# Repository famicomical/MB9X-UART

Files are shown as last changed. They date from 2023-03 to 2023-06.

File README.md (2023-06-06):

# MB9X-UART
Allows you to program the Fujitsu F2MC-16LX series processors using an RS-232C serial port connection. It uses a 12-pin connector for direct connection to the JVC DT-V series monitors and an optional 10-pin connection as described in Fujitsu documentation. Note: [programming the DT-V monitors](dt-vmod) requires modifying the Signal PWB. 

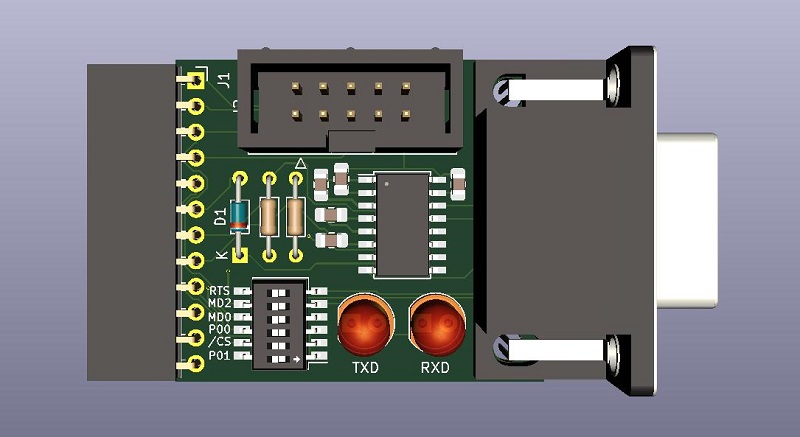
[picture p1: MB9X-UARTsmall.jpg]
PCB


The person assembling this board will need to procure their own USB to RS232-C cable and their own copy of the Fujitsu "FLASH MCU Programmer 16LX" software, which includes proprietary configuration files for the MCUs. I recommend installing [ISP-MB9X](https://isp-mb9x.sourceforge.net/) by Sergey Pinigin in addition to the [Fujitsu software](http://web.archive.org/web/20041020161858/http://www.fme.gsdc.de/products/utilitie.htm) to have some more fine control over programming operations.

## Example Usage
 - Identify the chip you are programming and set the DIP switches accordingly
   - Settings can be found in Fujitsu documentation. The /CS and RTS switches should stay ON.
 - Connect the USB-RS232C port to the assembled MB9X-UART PCB
    - extension of the USB cord is preferable to extending the RS232-C connection. in other words, connect the MB9X-UART directly to your adapter.
 - Connect the MB9X-UART to your target board, and turn on the power
 - Invoke the ISP-MB9X program from the command-line. 
   - For example: ```isp-mb9x.exe /1 /o4 /MB90F553A /b ROM /r```
uses serial port COM1 to dump the ROM from a Fujitsu MB90F553A running at 4MHz into a file called ROM. 
      - Caution: running the program without the /r command will erase the ROM from your MCU by default, so be careful!!
      - you must add the .mhx file extension manually as the isp-mb9x program will crash if you supply a file extension in the command line.
 - Wait for the read to complete being careful not to disturb the cables.
 - Power off your equipment and unplug the board

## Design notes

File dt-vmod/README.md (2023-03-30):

# Serial Programming mod for JVC DT-V Monitors
Some modification is needed to put the MCU in a JVC monitor into serial programming mode. 
We need a way to ground pin P01, and we will accomplish this by cutting an unused clock trace going to the 12-pin serial connector and replacing that signal with P01.
The UART-MB9X device will then be usable on the SIGNAL PWB. 

 - First, remove the 10 screws holding down the monitor cover
 - grabbing by the handles, wiggle the cover towards the back of the monitor slightly until you can see the metal lip that goes under the front bezel
 - Pull outwards from the handles to decouple the cover from the monitor and lift it straight up and away. place it where it won't be an obstacle
 - unplug the three cables from the signal PWB that go to the front button panel
 - remove the tally light cable and unplug the signal PWB from the I/O tower
 - gently remove the cables going from the signal PWB to the CRT neck board and the REMOTE board.
 - with the signal PWB now loose, place it on your workbench
 - flip it over and cut the trace shown in the following picture

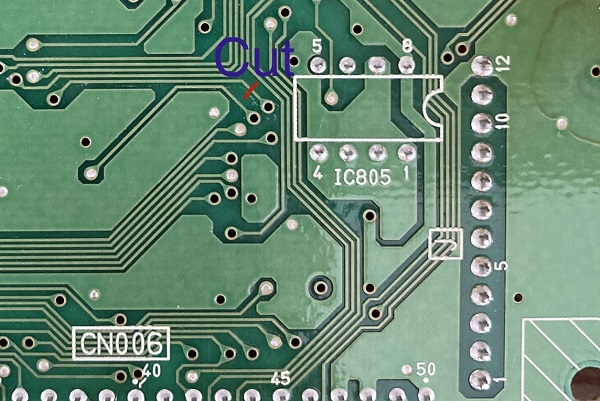
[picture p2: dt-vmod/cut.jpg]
cut

 - solder a small wire from the pad above R860 to the circled hole in the PCB.
 
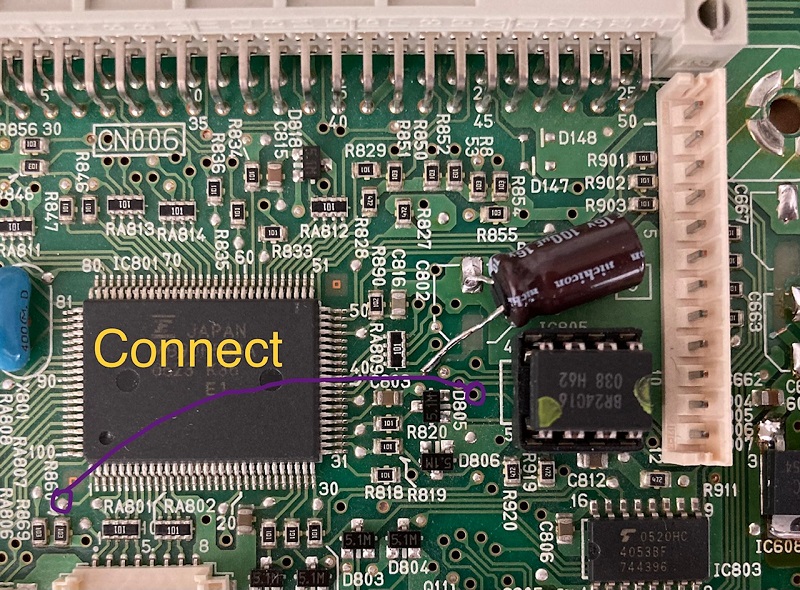
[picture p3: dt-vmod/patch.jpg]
patch
 
  - it may be necessary to remove resistor R859 for the MB9X-UART to deliver the reset pulse. you may reinstall it when done.
  
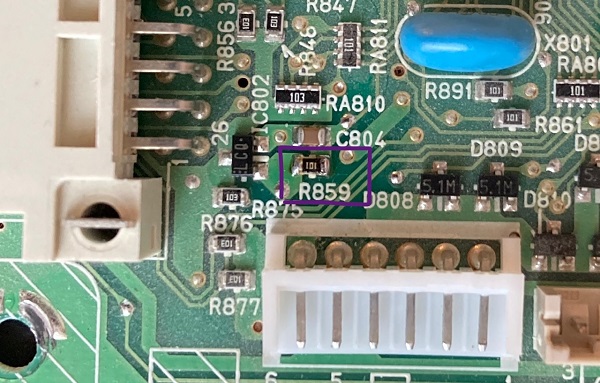
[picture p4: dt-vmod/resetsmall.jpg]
R859
  
 - take your assembled MB9X-UART board and use a razor blade or file to remove 0.5mm of material from each side of the 12-pin header
 
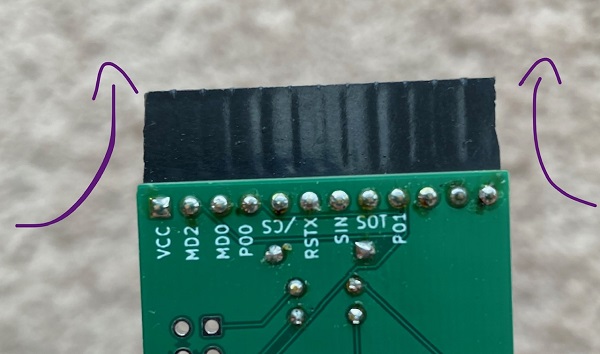
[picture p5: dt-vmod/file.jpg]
file
 
 - do this slowly and carefully until the MB9X-UART fits into connector J without too much force. a little force is OK.
 - Your signal board is now ready to be read/programmed. 
  - You can do this from the monitor service menu (untested) or using an external 5V supply plugged into the 3-pin connector C (preferred)
    - pin 2 is +5V and pin 3 is GND

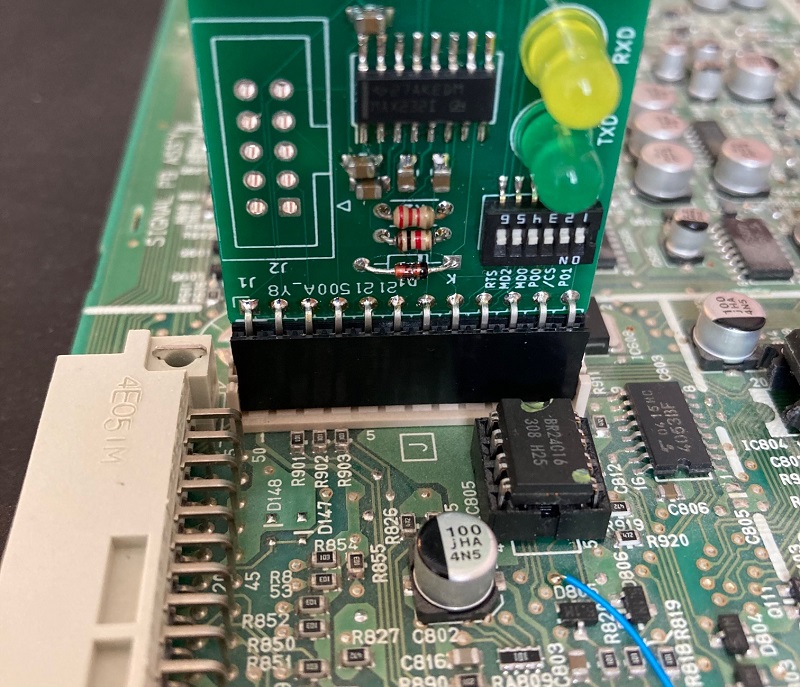
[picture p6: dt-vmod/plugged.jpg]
plugged


see the main readme for the command needed to dump the ROM. All the DIP switches should be set to ON.

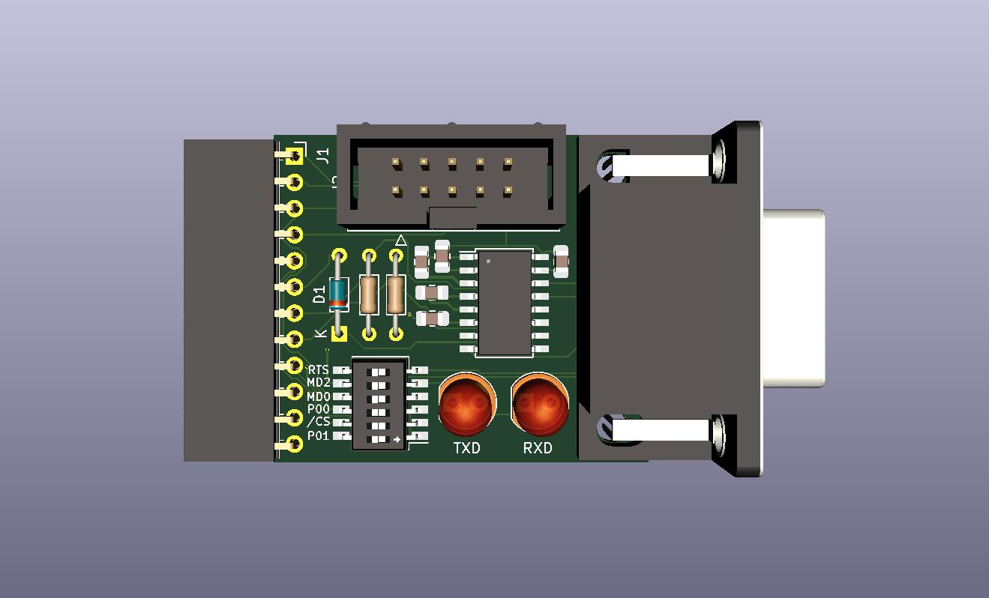
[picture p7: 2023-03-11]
MB9X-UART.jpg

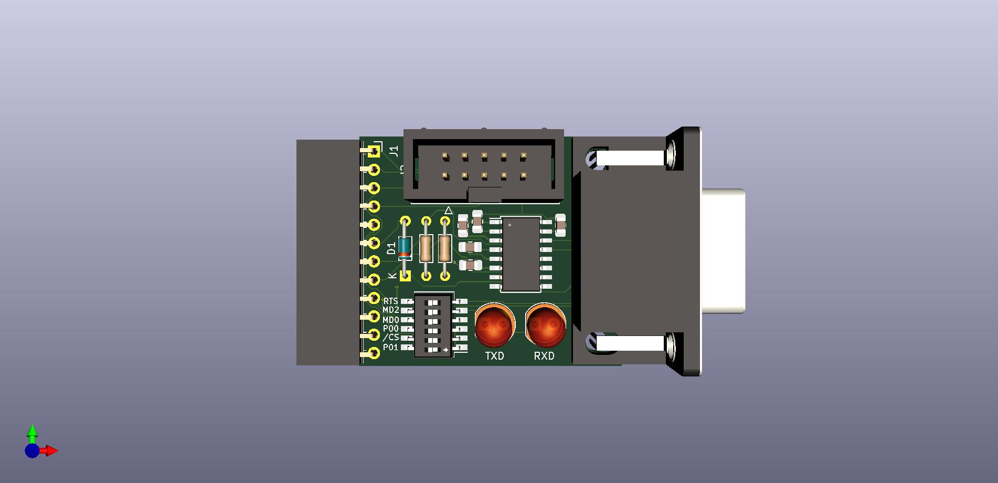
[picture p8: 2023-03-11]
MB9X-UART_org.jpg

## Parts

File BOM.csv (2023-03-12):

Index | Quantity | Part Number | Manufacturer Part Number | Description | Customer Reference | Unit Price | Extended Price
1 | 1 | 365-1182-ND | OVLFR3C7 | LED RED CLEAR 5MM T/H |  | 0.22 | $0.22
2 | 1 | 365-1190-ND | OVLGY0C9B9 | LED YELLOW CLEAR 5MM T/H |  | 0.23 | $0.23
3 | 1 | 296-26141-1-ND | MAX232IDR | IC TRANSCEIVER FULL 2/2 16SOIC |  | 0.93 | $0.93
4 | 1 | AE10921-ND | A-DF 09 A/KG-T2S | CONN D-SUB RCPT 9POS R/A SLDR |  | 0.78 | $0.78
5 | 1 | 1727-2907-1-ND | BAT85,113 | DIODE SCHOTTKY 30V 200MA DO34 |  | 0.45 | $0.45
6 | 1 | 1175-1609-ND | 3020-10-0100-00 | CONN HEADER VERT 10POS 2.54MM |  | 0.61 | $0.61
7 | 1 | S5448-ND | PPTC121LGBN-RC | CONN HDR 12POS 0.1 TIN PCB R/A |  | 0.8 | $0.80
8 | 5 | 1276-1029-1-ND | CL21B105KBFNNNE | CAP CER 1UF 50V X7R 0805 |  | 0.11 | $0.55
9 | 1 | 2223-DS05-127-2-06BK-SMT-CT-ND | DS05-127-2-06BK-SMT-TR | DIP SWITCH, SPST, 1.27 PITCH, FL |  | 1.59 | $1.59
 |  |  |  |  |  | subtotal | $5.72

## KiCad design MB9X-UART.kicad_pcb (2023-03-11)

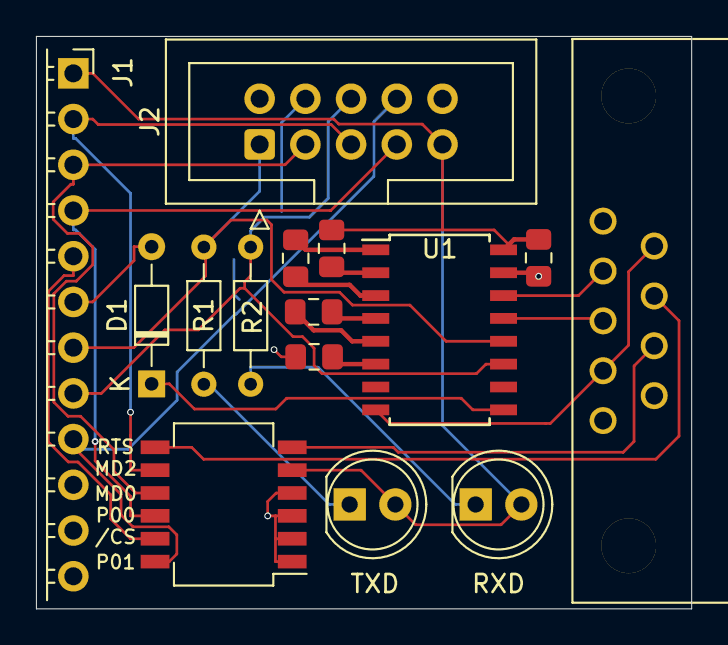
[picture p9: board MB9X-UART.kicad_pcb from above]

Board: 2 copper layers, 36.4 x 31.8 mm, 15 parts (0 on the bottom side), 24 nets.

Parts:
C1, C2, C3, C4, C5: 1u; C_0805_2012Metric_Pad1.15x1.40mm_HandSolder
D1: BAT85; D_DO-34_SOD68_P7.62mm_Horizontal
J1: Conn_01x12_Female; PinSocket_1x12_P2.54mm_Horizontal
J2: Conn_02x05_Odd_Even; IDC-Header_2x05_P2.54mm_Vertical
J3: DB9_Female; A-DF 09 A&slash_KG-T2S
R1, R2: 1k; R_Axial_DIN0204_L3.6mm_D1.6mm_P7.62mm_Horizontal
RXD: R_LED; LED_D5.0mm
SW1: SW_DIP_x06; SW_DIP_SPSTx06_Slide_Copal_CHS-06B_W7.62mm_P1.27mm
TXD: Y_LED; LED_D5.0mm
U1: MAX232I; SOIC-16W_5.3x10.2mm_P1.27mm

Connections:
/!CS: J1.5, SW1.11
/CTS: J3.8, SW1.6
/MD0: J1.3, J2.3, SW1.9
/MD2: J1.2, J2.5, SW1.8
/P00: J1.4, J2.7, SW1.10
/P01: J1.9, J2.8, SW1.12
/RSTX: D1.2, J1.6
/RTS: J3.7, SW1.7
/SIN: J1.7, J2.1, R1.1, U1.12
/SOT: J1.8, J2.6, R2.1, U1.11
GND: C2.2, C5.2, J1.12, J2.4, J3.5, SW1.1, SW1.2, SW1.3, SW1.4, U1.15
unnamed: C1.1, U1.1
unnamed: C1.2, U1.3
unnamed: C2.1, U1.6
unnamed: C3.1, U1.4
unnamed: C3.2, U1.5
unnamed: C4.2, U1.2
unnamed: D1.1, U1.9
unnamed: R1.2, TXD.1
unnamed: R2.2, RXD.1
unnamed: J3.2, U1.14
unnamed: J3.3, U1.13
unnamed: J3.4, J3.6, U1.8
VCC: C4.1, C5.1, J1.1, J2.9, RXD.2, SW1.5, TXD.2, U1.16

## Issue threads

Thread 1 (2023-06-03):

question about the resistors.

aluqard89, 2023-06-03:
I was going to build this board but i see that the components of R1 and R2 is missing in the BOM.csv.
So what iam asking for is what values are the resistors?

famicomical, 2023-06-04:
depends how bright you want your LED's to be. 330 to 1k ohm should be OK. most people who own a soldering iron would have some through hole resistors lying around so i didn't include them on the BOM.

aluqard89, 2023-06-04:
Thanks for the answer ,appreciate it 👍

Closed 2023-06-04.
